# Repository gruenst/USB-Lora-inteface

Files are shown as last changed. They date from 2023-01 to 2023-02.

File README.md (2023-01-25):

# USB-Lora-inteface
Circuitpython based LoRa USB stick, which allows browser based (GUI) serial communication via WebUSB to LoRa and back



## Purpose
Communication adapter to any remote LoRa satellite device, e.g. remote sensing over distances of several kilometers. The device can be used for collecting sensor data from widely distributed devices with a time resolution of seconds.

## Usage
 * Plug device in, opens up as USB stick (circuitpython)
 * Open .html file in Web Serial API compatible browser (Chrome, Edge, Opera; see https://developer.mozilla.org/en-US/docs/Web/API/Serial)
 * Use browser as GUI, connect to device and send/receive commands to/from device via serial interface
 * commands will be forwarded via LoRa RFM98W radio chip to remote device
 
 ## Content
 - PCB:             EAGLE Cad PCB files, list of components
 - Housing:         3D CAD files for 3D printing
 - Circuit Python:  Circuitpython .uf2, device code
 - GUI:             code.py for device, .html code with .js elements for GUI control
 - bootaloder:      Atmel SAMD bootloader for JLink (bootloader-usb_lora-v3.13.0.bin)
(https://learn.adafruit.com/adafruit-feather-m0-express-designed-for-circuit-py$

 ## Manual
 - Make PCB, solder components
 - flash bootloader using .bin file, e.g. via JLink, see https://learn.adafruit.com/how-to-program-samd-bootloaders
 - mount device via usb, put into bootloader mode, upload circuitpython .uf2 file
 - copy circuitpython8 lib elements to /lib directory on device
 - put code.py to device
 - upload .html file to device, adjust accordingly
 enjoy!
 
[Grn.Solar](https://www.grn.solar)
 
 Big shoutouts to [Adafruit](https://www.adafruit.com "Adafruit rocks"), all is based on their work.

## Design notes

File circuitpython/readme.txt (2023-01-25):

# Content:

 - Circuitpython .uf2 file, copy to device after basic bootloader is active
 - ports_atmel_boards directory for building circitpython, place to port/atmel/boards directory
   (https://learn.adafruit.com/building-circuitpython)
 - Adafruit circuitpython 8.x lib bundle, copy to /lib directory after .uf2 was installed

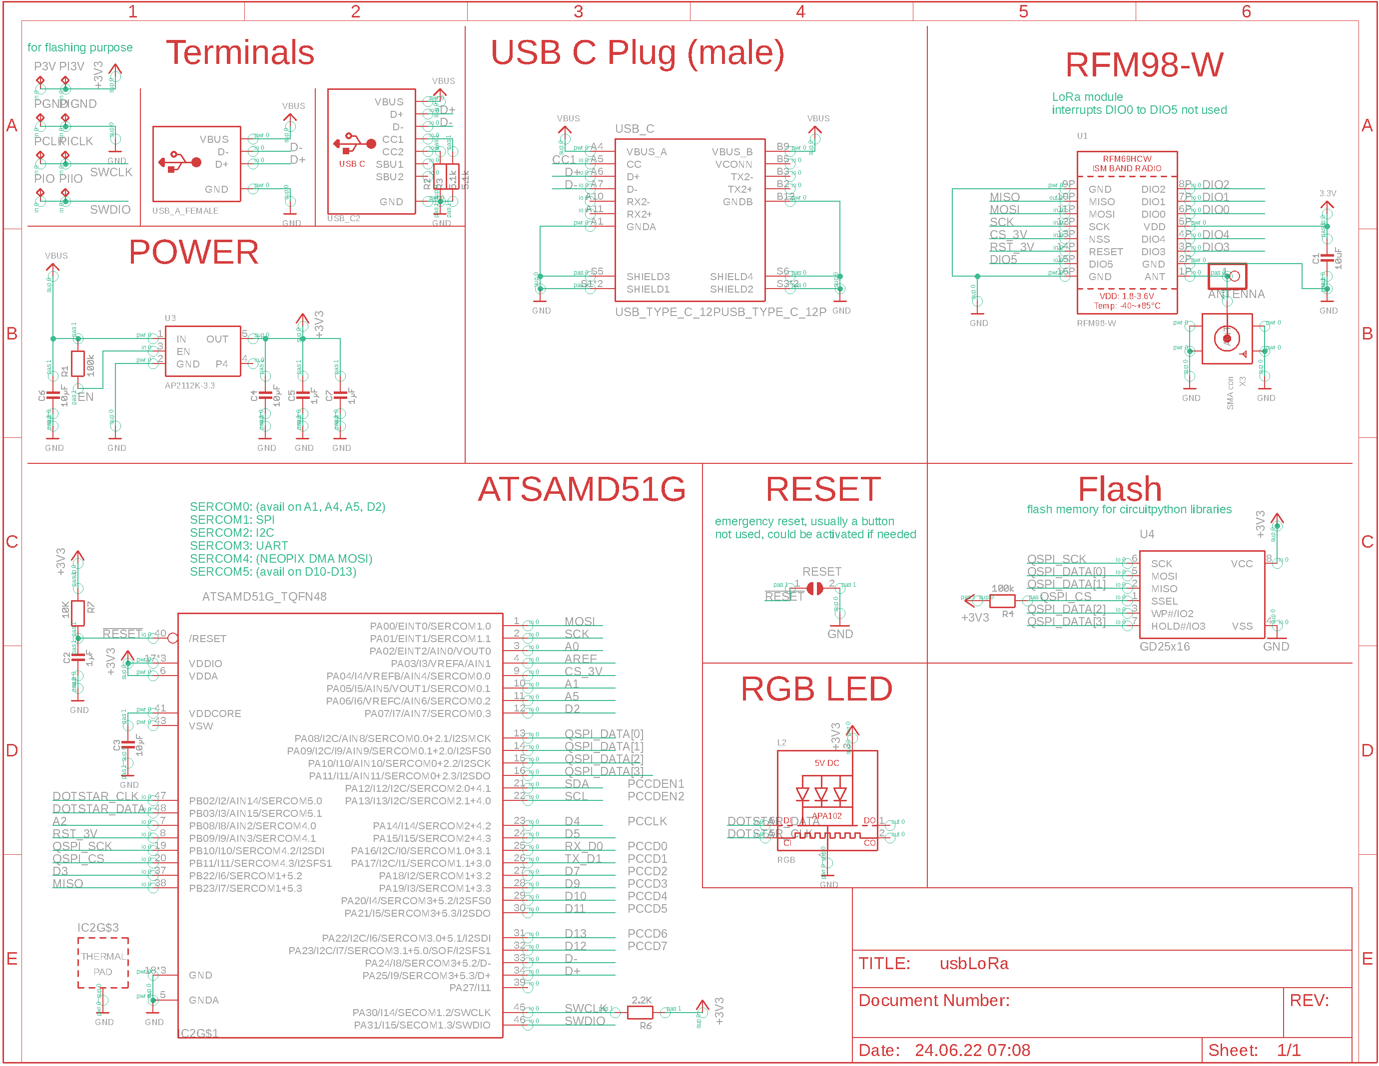
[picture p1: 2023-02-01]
PCB/schematic.png

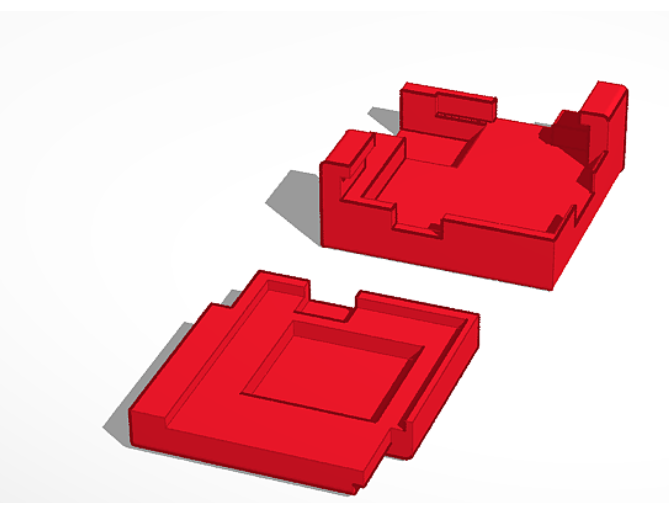
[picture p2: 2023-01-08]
Housing/UsbLora.png

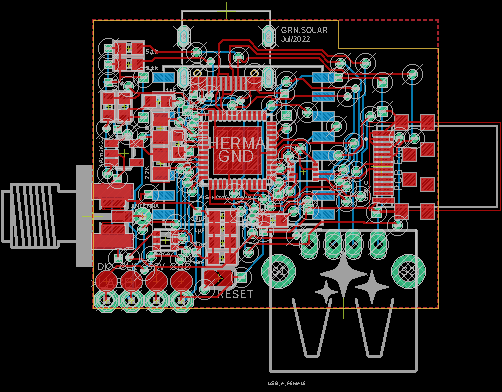
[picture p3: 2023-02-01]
PCB/board.png

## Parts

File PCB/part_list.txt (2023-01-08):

 - microcontroller ATSAMD51G19A-MU (TQFN48)
 - RGB LED APA102_2020
 - 3.3V regulator AP2112K-3.3TRG1
 - 16MBit Flash memory GD25Q16CEIGR
 - USB C plug connector (https://www.adafruit.com/product/4932)
 - USB C jack connector (https://www.adafruit.com/product/4458)
 - USB A jack connector (https://www.adafruit.com/product/2225)
 - SMA antenna edge launch (https://www.adafruit.com/product/1865)
 - LoRa 433MHz HopeRF RFM98W
 - 4x 10uF capacitor 0603 package
 - 3x 1uF capacitor 0603 package
 - 2x 100kO resistor 0603 package
 - 2x 5.1kO resistor 0603 package
 - 2x 2.2kO resistor 0805 package
 - 2x 10kO resistor 0805 package

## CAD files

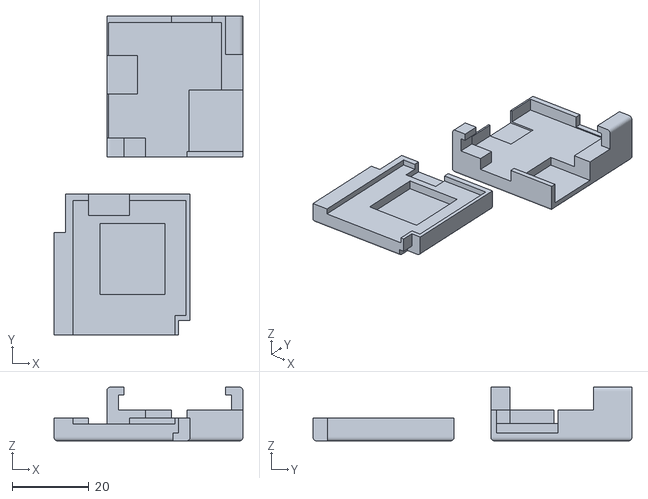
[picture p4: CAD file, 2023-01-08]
Housing/USB_LoRa.stl
49.1 x 82.9 x 14.0

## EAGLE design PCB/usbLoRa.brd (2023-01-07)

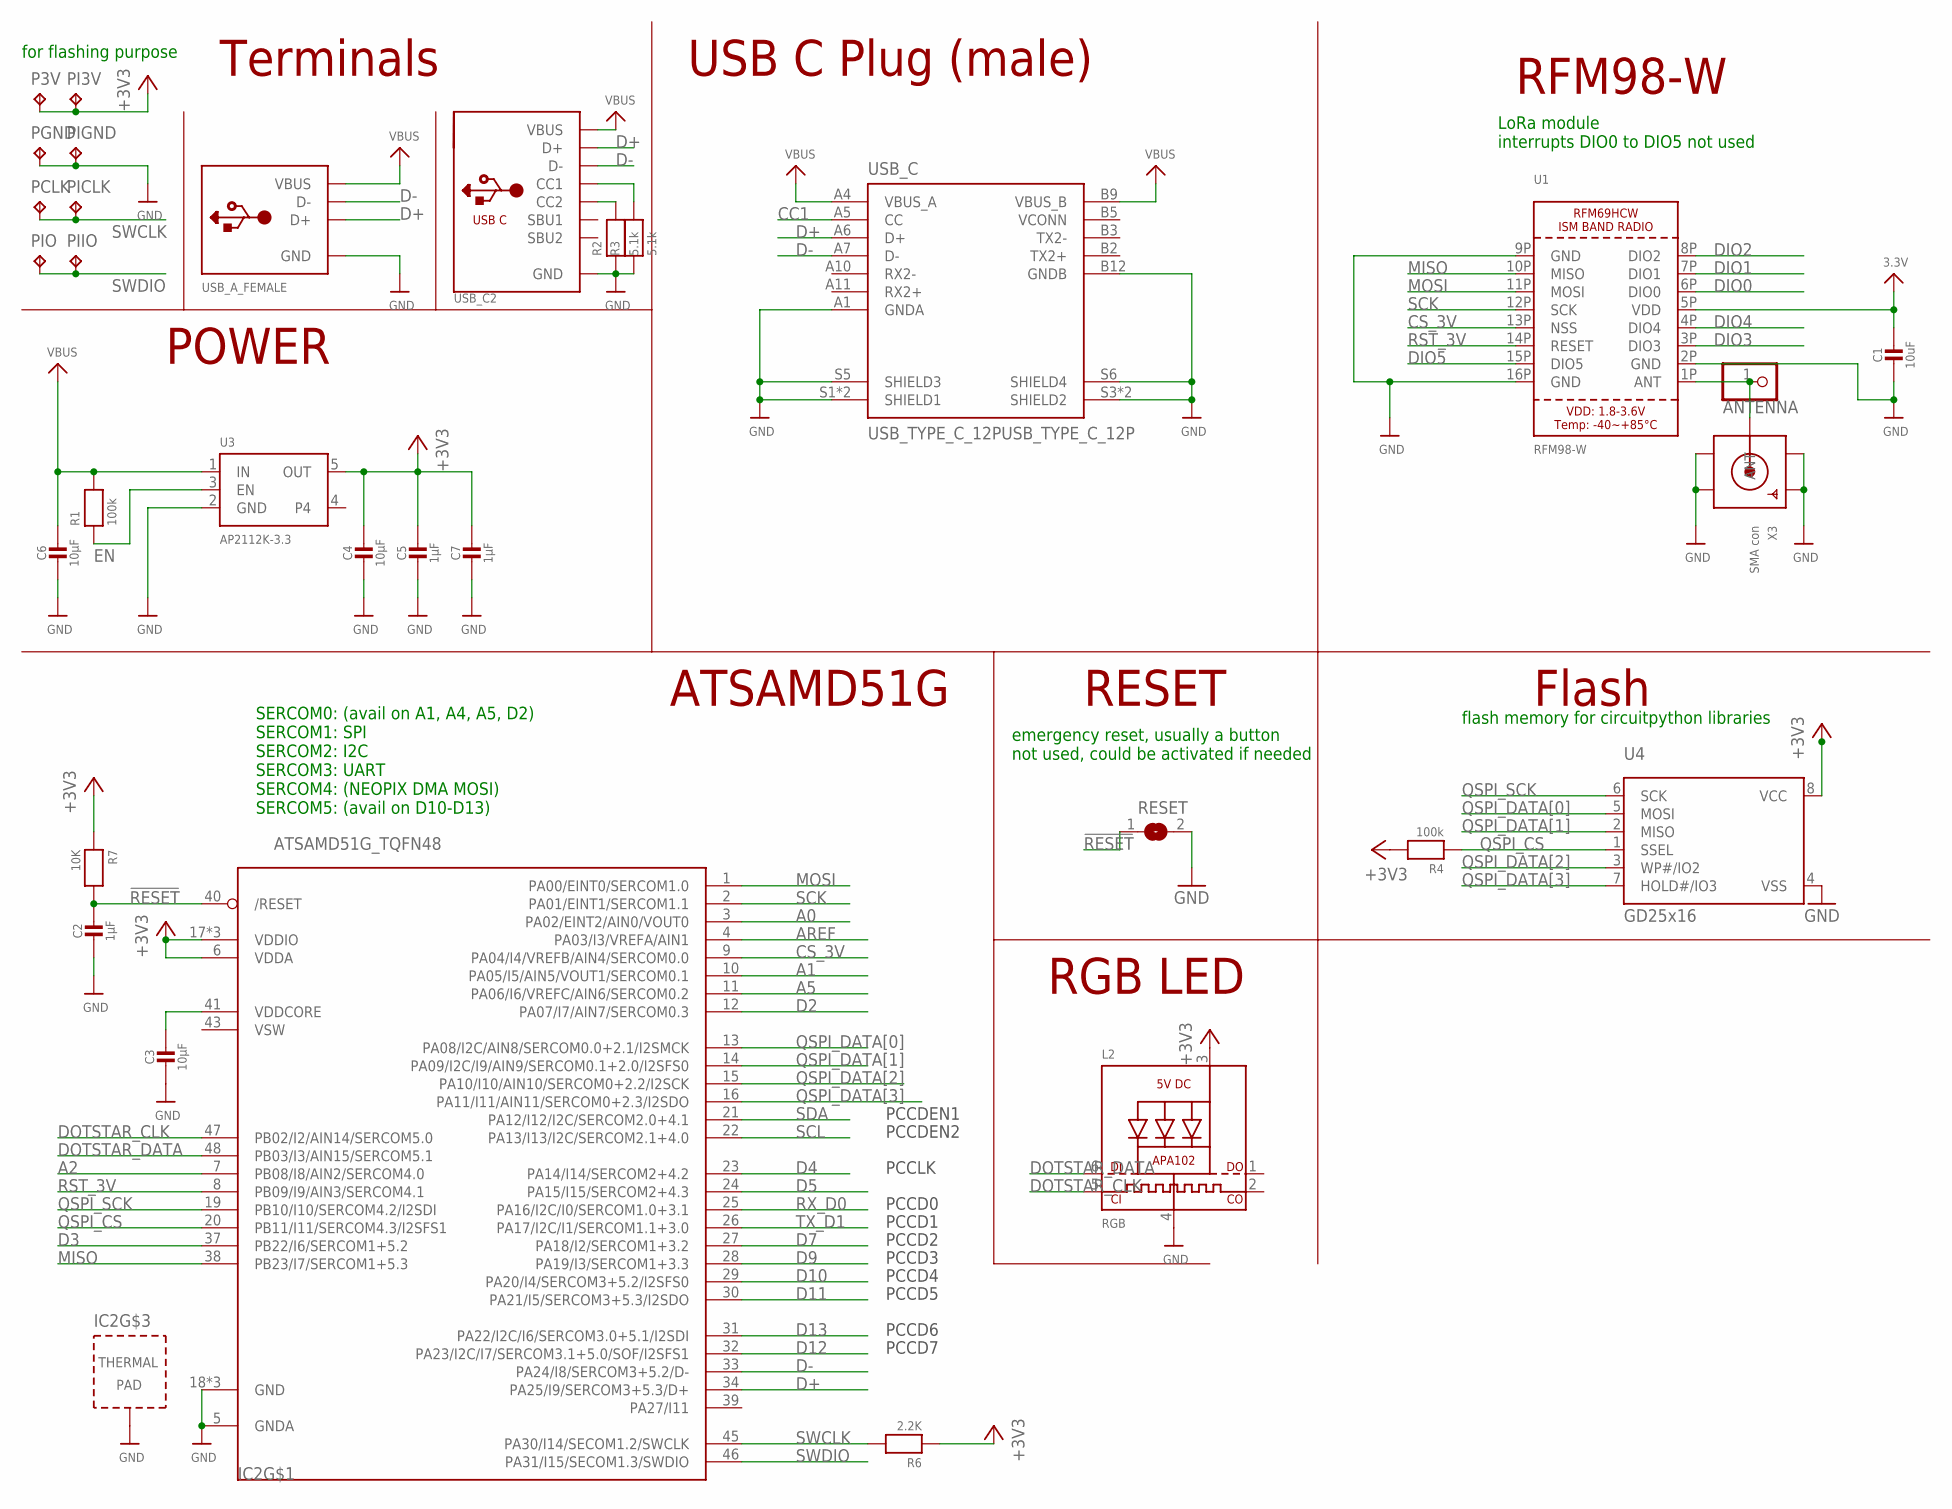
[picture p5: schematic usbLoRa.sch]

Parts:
ANTENNA: HEADER-1X1ROUND; 1X01_ROUND
C1: 10uF; 0603@1
C2, C5, C7: 1µF; 0603@1
C3, C4, C6: 10µF; 0603@1
IC2: ATSAMD51G_TQFN48; TQFN48_7MM
L2: RGB; APA102_2020
P3V: TPTP20R; TP20R
PCLK: TPTP20R; TP20R
PGND: TPTP20R; TP20R
PI3V: TPPAD1-13; P1-13
PICLK: TPPAD1-13; P1-13
PIGND: TPPAD1-13; P1-13
PIIO: TPPAD1-13; P1-13
PIO: TPTP20R; TP20R
R1, R4: 100k; 0603
R2, R3: 5.1k; 0603
R6: 2.2K; 0805
R7: 10K; 0805
RESET: SOLDERJUMPER; SOLDERJUMPER_ARROW_NOPASTE
U1: RFM98-W; RFMHCW_SMT
U3: AP2112K-3.3; SOT23-5
U4: GD25x16; USON8
USB_A: USB_A_FEMALE; USB_HOST-PTH
USB_C: USB_TYPE_C_12PUSB_TYPE_C_12P; USB_TYPE_C_12P
USB_C2: USB_C; USB_C_CUSB31-CFM2AX-01-X
X3: SMA con; SMA_EDGELAUNCH_UFL

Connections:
!RESET: C2.1, IC2.40 (/RESET), R7.2, RESET.1
+3V3: C1.1, C4.1, C5.1, C7.1, IC2.6 (VDDA), IC2.17 (VDDIO), IC2.36 (VDDIO), IC2.44 (VDDIO), L2.3 (VDD), P3V.TP, PI3V.TP, R4.2, R6.1, R7.1, U1.5P (VDD), U3.5 (OUT), U4.8 (VCC)
A0: IC2.3 (PA02/EINT2/AIN0/VOUT0)
A1: IC2.10 (PA05/I5/AIN5/VOUT1/SERCOM0.1)
A2: IC2.7 (PB08/I8/AIN2/SERCOM4.0)
A5: IC2.11 (PA06/I6/VREFC/AIN6/SERCOM0.2)
AREF: IC2.4 (PA03/I3/VREFA/AIN1)
CC1: R3.2, USB_C.A5 (CC), USB_C2.A5 (CC1)
CS_3V: IC2.9 (PA04/I4/VREFB/AIN4/SERCOM0.0), U1.13P (NSS)
D2: IC2.12 (PA07/I7/AIN7/SERCOM0.3)
D3: IC2.37 (PB22/I6/SERCOM1+5.2)
D4: IC2.23 (PA14/I14/SERCOM2+4.2)
D5: IC2.24 (PA15/I15/SERCOM2+4.3)
D7: IC2.27 (PA18/I2/SERCOM1+3.2)
D9: IC2.28 (PA19/I3/SERCOM1+3.3)
D10: IC2.29 (PA20/I4/SERCOM3+5.2/I2SFS0)
D11: IC2.30 (PA21/I5/SERCOM3+5.3/I2SDO)
D12: IC2.32 (PA23/I2C/I7/SERCOM3.1+5.0/SOF/I2SFS1)
D13: IC2.31 (PA22/I2C/I6/SERCOM3.0+5.1/I2SDI)
D+: IC2.34 (PA25/I9/SERCOM3+5.3/D+), USB_A.D+, USB_C.A6 (D+), USB_C2.A6 (D+), USB_C2.B6 (D+)
D-: IC2.33 (PA24/I8/SERCOM3+5.2/D-), USB_A.D-, USB_C.A7 (D-), USB_C2.A7 (D-), USB_C2.B7 (D-)
DIO0: U1.6P (DIO0)
DIO1: U1.7P (DIO1)
DIO2: U1.8P (DIO2)
DIO3: U1.3P (DIO3)
DIO4: U1.4P (DIO4)
DIO5: U1.15P (DIO5)
DOTSTAR_CLK: IC2.47 (PB02/I2/AIN14/SERCOM5.0), L2.5 (CKI)
DOTSTAR_DATA: IC2.48 (PB03/I3/AIN15/SERCOM5.1), L2.6 (DI)
EN: R1.1, U3.3 (EN)
GND: C1.2, C2.2, C3.2, C4.2, C5.2, C6.2, C7.2, IC2.5 (GNDA), IC2.18 (GND), IC2.35 (GND), IC2.42 (GND), IC2.THERMAL (TP), L2.4 (GND), PGND.TP, PIGND.TP, R2.1, R3.1, RESET.2, U1.2P (GND), U1.9P (GND), U1.16P (GND), U3.2 (GND), U4.4 (VSS), USB_A.GND, USB_C.A1 (GNDA), USB_C.B12 (GNDB), USB_C.S1 (SHIELD1), USB_C.S2 (SHIELD1), USB_C.S3 (SHIELD2), USB_C.S4 (SHIELD2), USB_C.S5 (SHIELD3), USB_C.S6 (SHIELD4), USB_C2.A1B12 (GND), USB_C2.B1A12 (GND), X3.GND@1 (GND1), X3.GND@2 (GND2), X3.GND@3 (GND3), X3.GND@4 (GND4)
MISO: IC2.38 (PB23/I7/SERCOM1+5.3), U1.10P (MISO)
MOSI: IC2.1 (PA00/EINT0/SERCOM1.0), U1.11P (MOSI)
unnamed: ANTENNA.1, U1.1P (ANT), X3.P (ANT)
unnamed: R2.2, USB_C2.B5 (CC2)
QSPI_CS: IC2.20 (PB11/I11/SERCOM4.3/I2SFS1), R4.1, U4.1 (SSEL)
QSPI_DATA[0]: IC2.13 (PA08/I2C/AIN8/SERCOM0.0+2.1/I2SMCK), U4.5 (MOSI)
QSPI_DATA[1]: IC2.14 (PA09/I2C/I9/AIN9/SERCOM0.1+2.0/I2SFS0), U4.2 (MISO)
QSPI_DATA[2]: IC2.15 (PA10/I10/AIN10/SERCOM0+2.2/I2SCK), U4.3 (WP#/IO2)
QSPI_DATA[3]: IC2.16 (PA11/I11/AIN11/SERCOM0+2.3/I2SDO), U4.7 (HOLD#/IO3)
QSPI_SCK: IC2.19 (PB10/I10/SERCOM4.2/I2SDI), U4.6 (SCK)
RST_3V: IC2.8 (PB09/I9/AIN3/SERCOM4.1), U1.14P (RESET)
RX_D0: IC2.25 (PA16/I2C/I0/SERCOM1.0+3.1)
SCK: IC2.2 (PA01/EINT1/SERCOM1.1), U1.12P (SCK)
SCL: IC2.22 (PA13/I13/I2C/SERCOM2.1+4.0)
SDA: IC2.21 (PA12/I12/I2C/SERCOM2.0+4.1)
SWCLK: IC2.45 (PA30/I14/SECOM1.2/SWCLK), PCLK.TP, PICLK.TP, R6.2
SWDIO: IC2.46 (PA31/I15/SECOM1.3/SWDIO), PIIO.TP, PIO.TP
TX_D1: IC2.26 (PA17/I2C/I1/SERCOM1.1+3.0)
VBUS: C6.1, R1.2, U3.1 (IN), USB_A.VBUS, USB_C.A4 (VBUS_A), USB_C.B9 (VBUS_B), USB_C2.A4B9 (VBUS), USB_C2.B4A9 (VBUS)
VDDCORE1: C3.1, IC2.41 (VDDCORE)
VSW: IC2.43 (VSW)

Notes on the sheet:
Terminals
RFM98-W
POWER
RESET
Flash
RGB LED
LoRa module interrupts DIO0 to DIO5 not used
emergency reset, usually a button not used, could be activated if needed
flash memory for circuitpython libraries
for flashing purpose
SERCOM0: (avail on A1, A4, A5, D2) SERCOM1: SPI SERCOM2: I2C SERCOM3: UART SERCOM4: (NEOPIX DMA MOSI) SERCOM5: (avail on D10-D13)
PCCDEN1
PCCDEN2
PCCD0
PCCD1
PCCD2
PCCD3
PCCD4
PCCD5
PCCD6
PCCD7
PCCLK
ATSAMD51G
USB C Plug (male)

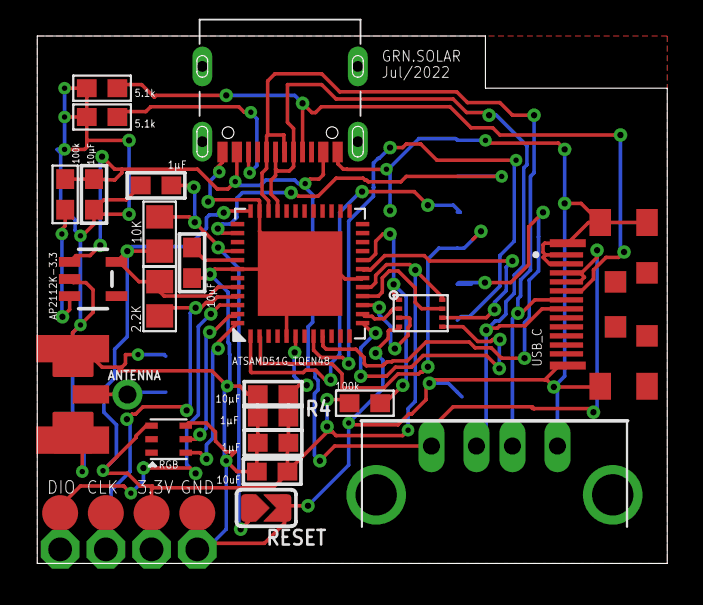
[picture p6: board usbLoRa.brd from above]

Board: 2 copper layers, 35.0 x 29.3 mm, 32 parts (1 on the bottom side), 26 nets.

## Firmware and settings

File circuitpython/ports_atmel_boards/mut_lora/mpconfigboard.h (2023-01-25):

#define MICROPY_HW_BOARD_NAME "MuT_LoRa"
#define MICROPY_HW_MCU_NAME "samd51g19"

#define CIRCUITPY_MCU_FAMILY samd51

// This is for Rev B
#define MICROPY_HW_LED_STATUS   (&pin_PA22)

#define MICROPY_HW_APA102_MOSI   (&pin_PB03)
#define MICROPY_HW_APA102_SCK    (&pin_PB02)

#define DEFAULT_I2C_BUS_SCL (&pin_PA13)
#define DEFAULT_I2C_BUS_SDA (&pin_PA12)

#define DEFAULT_SPI_BUS_SCK (&pin_PA01)
#define DEFAULT_SPI_BUS_MOSI (&pin_PA00)
#define DEFAULT_SPI_BUS_MISO (&pin_PB23)

#define DEFAULT_UART_BUS_RX (&pin_PA16)
#define DEFAULT_UART_BUS_TX (&pin_PA17)

// USB is always used internally so skip the pin objects for it.
#define IGNORE_PIN_PA24     1
#define IGNORE_PIN_PA25     1

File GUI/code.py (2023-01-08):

# Test program for Alex - sends command "CL5" every 5 sec., prints answer - enjoy!
import time
import board
import busio
import digitalio
import adafruit_rfm9x
from adafruit_ads1x15.analog_in import AnalogIn
import sys
import supervisor
import usb_cdc
#storage.remount("/", False)
RADIO_FREQ_MHZ = 433.0   # LORA frequency 433 MHz

# Define pins connected to the chip, A4 and A3, initialize SPI
CS = digitalio.DigitalInOut(board.A4)
RESET = digitalio.DigitalInOut(board.A3)
spi = busio.SPI(board.SCK, MOSI=board.MOSI, MISO=board.MISO)

# Initialze LORA
rfm9x = adafruit_rfm9x.RFM9x(spi, CS, RESET, RADIO_FREQ_MHZ)
rfm9x.tx_power = 23   #transmission power: 23dB
rfm9x.signal_bandwidth = 62500
rfm9x.coding_rate = 8
rfm9x.spreading_factor = 9
rfm9x.enable_crc = True

#startTime = time.monotonic()  #start timer

def read_serial(serial):
    available = serial.in_waiting
    text = ""
    while available:
        raw = serial.read(available)
        text = raw.decode("utf-8")
        available = serial.in_waiting
    return text

serial = usb_cdc.console
inText = ""
while True:
    inText += read_serial(serial)
    if inText.endswith("\n"):
        if (inText.find("measure") > -1):
            rfm9x.send("CL5",destination=0,node=0,identifier=0,flags=0)
            packet = rfm9x.receive(timeout=2)
            if packet is not None:
              try:
                packetText = str(packet, 'ascii')
              except:
                packetText = "<gibberish>"
              print(packetText)
        inText = ""


#      rfm9x.send("CL5",destination=0,node=0,identifier=0,flags=0)
#      packet = rfm9x.receive(timeout=2)
#      if packet is not None:
#        try:
#          packetText = str(packet, 'ascii')
#        except:
#          packetText = "<gibberish>"
#      print(packetText)



    #send out measurement signal every 5 seconds
#    if (time.monotonic() - startTime >= 5):
#      rfm9x.send("CL5",destination=0,node=0,identifier=0,flags=0)
#      print("measure command sent")
#      startTime = time.monotonic()
#    packet = rfm9x.receive(timeout=2)
#    if packet is not None:
#        try:
#          packetText = str(packet, 'ascii')
#        except:
#          packetText = "<gibberish>"
#        printText = "received: " + packetText
#        print(printText)


    #if supervisor.runtime.serial_bytes_available:
    #    value = input().strip()
    #    # Sometimes Windows sends an extra (or missing) newline - ignore them
    #    if value == "":
    #        continue
    #    print("RX: {}".format(value))

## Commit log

2023-01-07 Create PCB
2023-02-01 eagle cad files

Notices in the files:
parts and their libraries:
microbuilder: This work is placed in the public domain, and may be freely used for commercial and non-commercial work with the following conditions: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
